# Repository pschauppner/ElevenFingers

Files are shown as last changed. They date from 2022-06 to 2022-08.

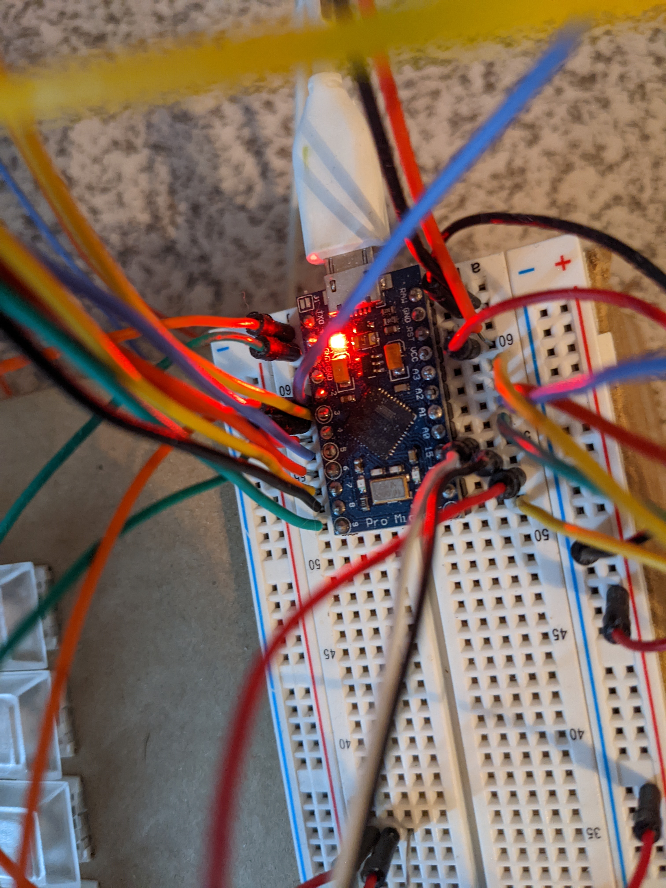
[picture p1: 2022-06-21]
pictures/PXL_20220617_202713375.jpg

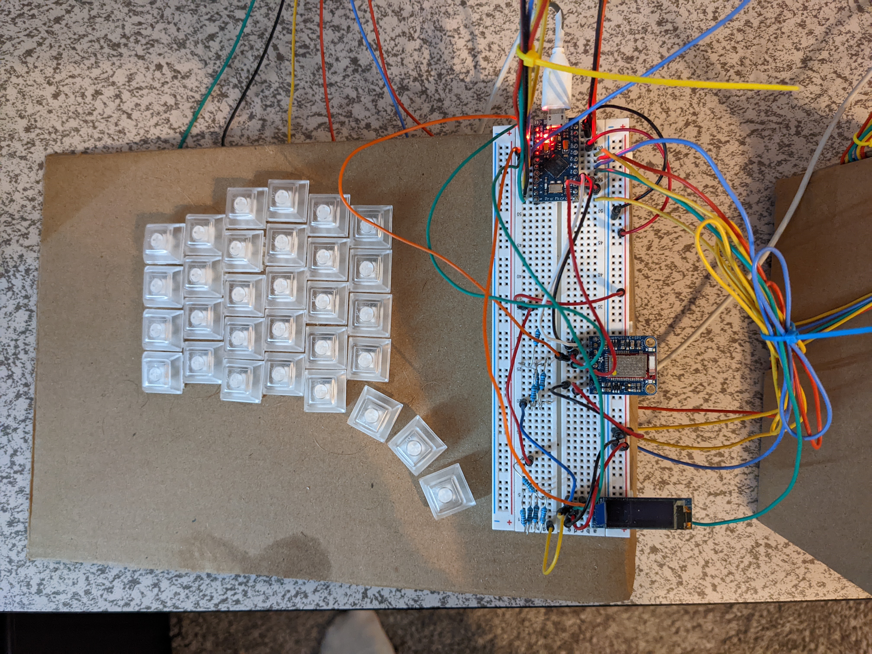
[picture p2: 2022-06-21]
pictures/PXL_20220617_202623680.jpg

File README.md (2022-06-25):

# ElevenFingers
An ergonomic split keyboard

## Notes/assumptions for this build
Encoder will be swapped in software (vice having a reverse footprint)
Most components are flipped for right side, LEDs are flipped AND rotated 180 degrees so that routes with vias can be more direct

## Issues and planned work
- Bluetooth is tempermental with pull down resistors - no longer needed for my current setup - plan to remove
- Source code has to get modified for flashing left half and right half - not great
- some software layout issues (no semi colon, tilde, grave, function keys...) - could really expand on use of layers
- OLED can be more helpful
- I don't like the sound of clicky keys - plan to switch to tactile
- hotswap sockets were a bad idea - they made connections less reliable (and I'm not a big keyswapper anyway)
- Next: case + PCB, better wires
- a power switch, and/or a reset button might be nice

## Project Navigation

### keyboard-layout-editor
This folder contains the json for uploading in the 'Raw Data' tab of [keyboard-layout-editor.com](http://www.keyboard-layout-editor.com/)
It's rotated right because it was easier for dealing with a columnar stagger this way (keyboard-layout-editor syntax is row-based, assuming each "row" is at the same vertical offset).

### qmk_firmware/keyboards/ElevenFingers
Contains the source code that would go under 'keyboards' in the qmk_firmware root directory (https://github.com/qmk/qmk_firmware)

Note - my idea is that any customizations to qmk will be added here with a script to copy it into the qmk repository.  (Why does QMK host so many individual keyboard source files?)

### fabrication
This keyboard is currently a cardboard prototype.  The svg was used as a template to cutout squares in a piece of cardboard.  In the future this will contain drawings for case and mounting plates.  Note I used http://builder.swillkb.com/ with the MX switch type (and otherwise default settings) to generate this SVG.

### circuitry
This keyboard was handwired.  This folder contains notes and pictures of the wiring.  In the future, this will contain PCB design files.

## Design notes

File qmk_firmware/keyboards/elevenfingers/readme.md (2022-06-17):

custom built split keyboard
cardboard prototype
Apr 17 2021
Paul Schauppner

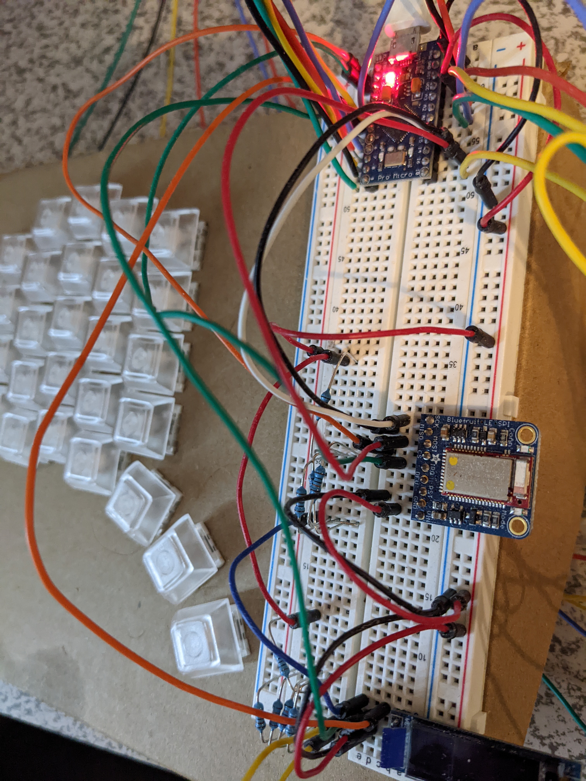
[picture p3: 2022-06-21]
pictures/PXL_20220617_202722207.MP.jpg

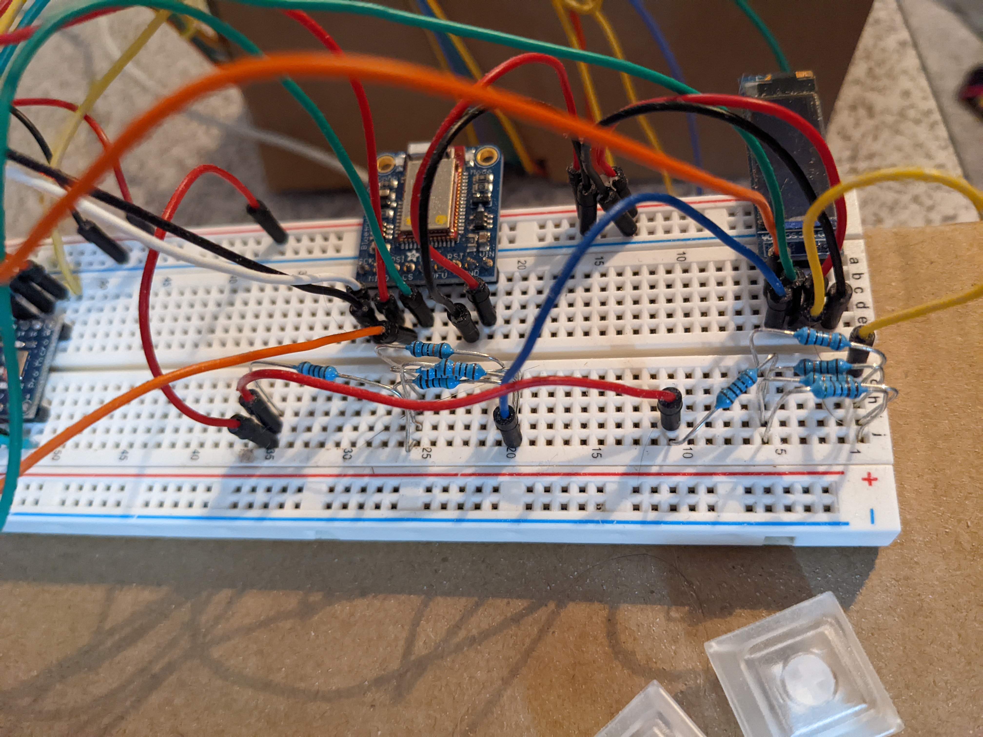
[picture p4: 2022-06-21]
pictures/PXL_20220617_202728293.MP.jpg

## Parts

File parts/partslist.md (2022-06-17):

100 - Kailh Hot-swap sockets (https://www.aliexpress.com/item/2255800865526224.html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)
2 - ATmega32U4 5V ProMicro (https://www.aliexpress.com/item/2251832803139947.html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)
70 - Kailh Box White RGB SMD switches (https://www.aliexpress.com/item/2251832649497008.html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)
200 - 1N4148 Diodes (https://www.aliexpress.com/item/2251832473773777.html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)
1 - SSD1306 OLED display (https://www.aliexpress.com/item/2255800842069517.html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)
60 - 1u PBT Blank Translucent Keycaps (https://www.aliexpress.com/item/2255800293762005.html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)
1 - Adafruit Bluefruit LE SPI

Wiring
Soldering Kit
Breadboards
Exacto Knife
Firm cardboard
Resistors
MicroUSB cable

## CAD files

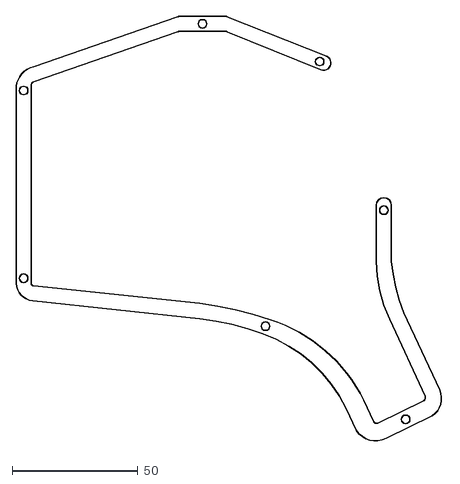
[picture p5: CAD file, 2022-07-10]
circuitry/case-files/ElevenFingers-User_2.dxf
169.8 x 169.7

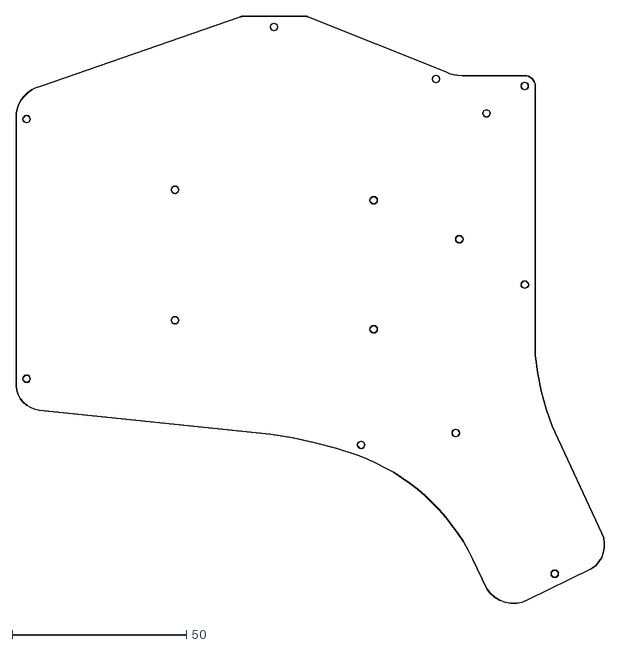
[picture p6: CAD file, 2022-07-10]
circuitry/case-files/ElevenFingers-User_4.dxf
169.8 x 169.7

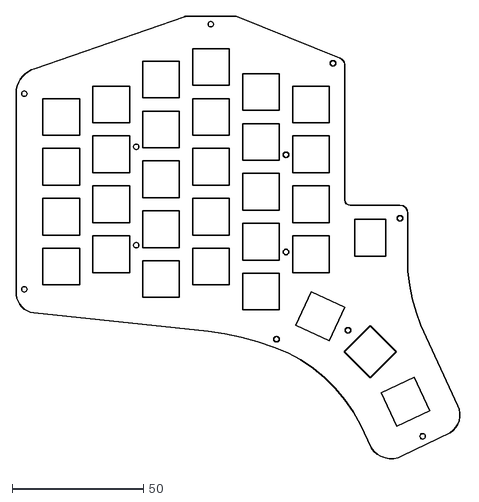
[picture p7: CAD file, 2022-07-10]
circuitry/case-files/ElevenFingers-User_3.dxf
169.8 x 169.7

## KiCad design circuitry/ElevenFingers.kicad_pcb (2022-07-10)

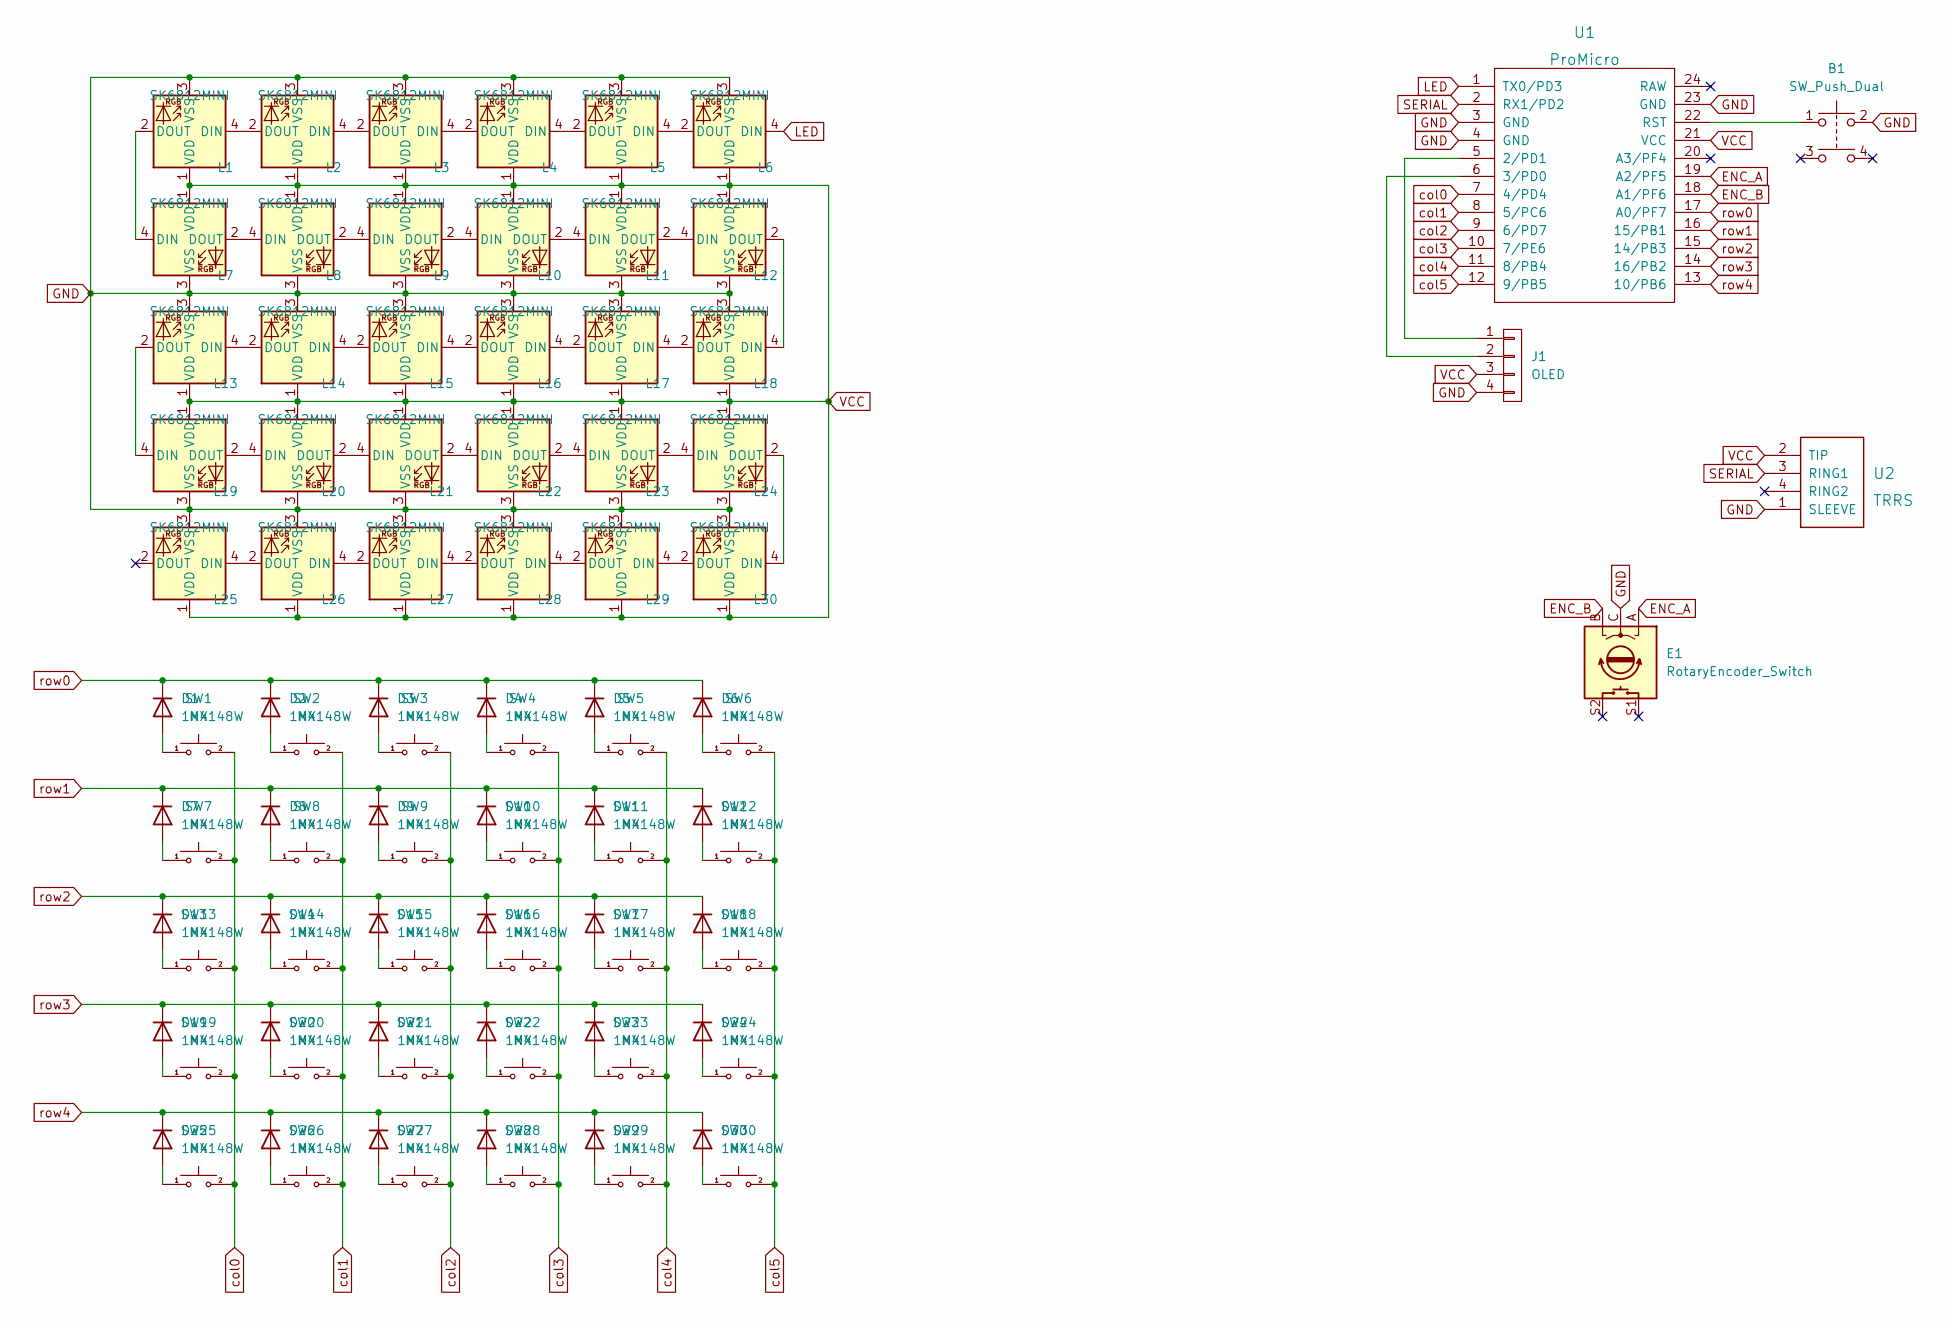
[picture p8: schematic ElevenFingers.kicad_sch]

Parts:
B1: SW_Push_Dual; Arduino_Pushbutton
D1, D2, D3, D4, D5, D6, D7, D8, D9, D10, D11, D12, D13, D14, D15, D16, D17, D18, D19, D20, D21, D22, D23, D24, D25, D26, D27, D28, D29, D30: 1N4148W; D_SOD-123
E1: RotaryEncoder_Switch; RotaryEncoder_EC11
J1: OLED; OLED_4Pin
L1, L2, L3, L4, L5, L6, L7, L8, L9, L10, L11, L12, L13, L14, L15, L16, L17, L18, L19, L20, L21, L22, L23, L24, L25, L26, L27, L28, L29, L30: SK6812MINI; LED_SK6812MINI_PLCC4_3.5x3.5mm_P1.75mm
SW1, SW2, SW3, SW4, SW5, SW6, SW7, SW8, SW9, SW10, SW11, SW12, SW13, SW14, SW15, SW16, SW17, SW18, SW19, SW20, SW21, SW22, SW23, SW24, SW25, SW26, SW27, SW28, SW29, SW30: MX; SW_Cherry_MX_1.00u_PCB
U1: ProMicro
U2: TRRS; TRRS-PJ-320A

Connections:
ENC_A: E1.A, U1.19 (A2/PF5)
ENC_B: E1.B, U1.18 (A1/PF6)
GND: B1.2, E1.C, J1.4, L1.3 (VSS), L2.3 (VSS), L3.3 (VSS), L4.3 (VSS), L5.3 (VSS), L6.3 (VSS), L7.3 (VSS), L8.3 (VSS), L9.3 (VSS), L10.3 (VSS), L11.3 (VSS), L12.3 (VSS), L13.3 (VSS), L14.3 (VSS), L15.3 (VSS), L16.3 (VSS), L17.3 (VSS), L18.3 (VSS), L19.3 (VSS), L20.3 (VSS), L21.3 (VSS), L22.3 (VSS), L23.3 (VSS), L24.3 (VSS), L25.3 (VSS), L26.3 (VSS), L27.3 (VSS), L28.3 (VSS), L29.3 (VSS), L30.3 (VSS), U1.3 (GND), U1.4 (GND), U1.23 (GND), U2.1 (SLEEVE)
LED: L6.4 (DIN), U1.1 (TX0/PD3)
unnamed: B1.1, U1.22 (RST)
unnamed: D1.2 (A), SW1.1
unnamed: D2.2 (A), SW2.1
unnamed: D3.2 (A), SW3.1
unnamed: D4.2 (A), SW4.1
unnamed: D5.2 (A), SW5.1
unnamed: D6.2 (A), SW6.1
unnamed: D7.2 (A), SW7.1
unnamed: D8.2 (A), SW8.1
unnamed: D9.2 (A), SW9.1
unnamed: D10.2 (A), SW10.1
unnamed: D11.2 (A), SW11.1
unnamed: D12.2 (A), SW12.1
unnamed: D13.2 (A), SW13.1
unnamed: D14.2 (A), SW14.1
unnamed: D15.2 (A), SW15.1
unnamed: D16.2 (A), SW16.1
unnamed: D17.2 (A), SW17.1
unnamed: D18.2 (A), SW18.1
unnamed: D19.2 (A), SW19.1
unnamed: D20.2 (A), SW20.1
unnamed: D21.2 (A), SW21.1
unnamed: D22.2 (A), SW22.1
unnamed: D23.2 (A), SW23.1
unnamed: D24.2 (A), SW24.1
unnamed: D25.2 (A), SW25.1
unnamed: D26.2 (A), SW26.1
unnamed: D27.2 (A), SW27.1
unnamed: D28.2 (A), SW28.1
unnamed: D29.2 (A), SW29.1
unnamed: D30.2 (A), SW30.1
unnamed: J1.1, U1.5 (2/PD1)
unnamed: J1.2, U1.6 (3/PD0)
unnamed: L1.2 (DOUT), L7.4 (DIN)
unnamed: L1.4 (DIN), L2.2 (DOUT)
unnamed: L2.4 (DIN), L3.2 (DOUT)
unnamed: L3.4 (DIN), L4.2 (DOUT)
unnamed: L4.4 (DIN), L5.2 (DOUT)
unnamed: L5.4 (DIN), L6.2 (DOUT)
unnamed: L7.2 (DOUT), L8.4 (DIN)
unnamed: L8.2 (DOUT), L9.4 (DIN)
unnamed: L10.2 (DOUT), L11.4 (DIN)
unnamed: L9.2 (DOUT), L10.4 (DIN)
unnamed: L11.2 (DOUT), L12.4 (DIN)
unnamed: L12.2 (DOUT), L18.4 (DIN)
unnamed: L13.2 (DOUT), L19.4 (DIN)
unnamed: L13.4 (DIN), L14.2 (DOUT)
unnamed: L14.4 (DIN), L15.2 (DOUT)
unnamed: L15.4 (DIN), L16.2 (DOUT)
unnamed: L16.4 (DIN), L17.2 (DOUT)
unnamed: L17.4 (DIN), L18.2 (DOUT)
unnamed: L19.2 (DOUT), L20.4 (DIN)
unnamed: L20.2 (DOUT), L21.4 (DIN)
unnamed: L21.2 (DOUT), L22.4 (DIN)
unnamed: L22.2 (DOUT), L23.4 (DIN)
unnamed: L23.2 (DOUT), L24.4 (DIN)
unnamed: L24.2 (DOUT), L30.4 (DIN)
unnamed: L25.4 (DIN), L26.2 (DOUT)
unnamed: L26.4 (DIN), L27.2 (DOUT)
unnamed: L27.4 (DIN), L28.2 (DOUT)
unnamed: L28.4 (DIN), L29.2 (DOUT)
unnamed: L29.4 (DIN), L30.2 (DOUT)
SERIAL: U1.2 (RX1/PD2), U2.3 (RING1)
VCC: J1.3, L1.1 (VDD), L2.1 (VDD), L3.1 (VDD), L4.1 (VDD), L5.1 (VDD), L6.1 (VDD), L7.1 (VDD), L8.1 (VDD), L9.1 (VDD), L10.1 (VDD), L11.1 (VDD), L12.1 (VDD), L13.1 (VDD), L14.1 (VDD), L15.1 (VDD), L16.1 (VDD), L17.1 (VDD), L18.1 (VDD), L19.1 (VDD), L20.1 (VDD), L21.1 (VDD), L22.1 (VDD), L23.1 (VDD), L24.1 (VDD), L25.1 (VDD), L26.1 (VDD), L27.1 (VDD), L28.1 (VDD), L29.1 (VDD), L30.1 (VDD), U1.21 (VCC), U2.2 (TIP)
col0: SW1.2, SW7.2, SW13.2, SW19.2, SW25.2, U1.7 (4/PD4)
col1: SW2.2, SW8.2, SW14.2, SW20.2, SW26.2, U1.8 (5/PC6)
col2: SW3.2, SW9.2, SW15.2, SW21.2, SW27.2, U1.9 (6/PD7)
col3: SW4.2, SW10.2, SW16.2, SW22.2, SW28.2, U1.10 (7/PE6)
col4: SW5.2, SW11.2, SW17.2, SW23.2, SW29.2, U1.11 (8/PB4)
col5: SW6.2, SW12.2, SW18.2, SW24.2, SW30.2, U1.12 (9/PB5)
row0: D1.1 (K), D2.1 (K), D3.1 (K), D4.1 (K), D5.1 (K), D6.1 (K), U1.17 (A0/PF7)
row1: D7.1 (K), D8.1 (K), D9.1 (K), D10.1 (K), D11.1 (K), D12.1 (K), U1.16 (15/PB1)
row2: D13.1 (K), D14.1 (K), D15.1 (K), D16.1 (K), D17.1 (K), D18.1 (K), U1.15 (14/PB3)
row3: D19.1 (K), D20.1 (K), D21.1 (K), D22.1 (K), D23.1 (K), D24.1 (K), U1.14 (16/PB2)
row4: D25.1 (K), D26.1 (K), D27.1 (K), D28.1 (K), D29.1 (K), D30.1 (K), U1.13 (10/PB6)

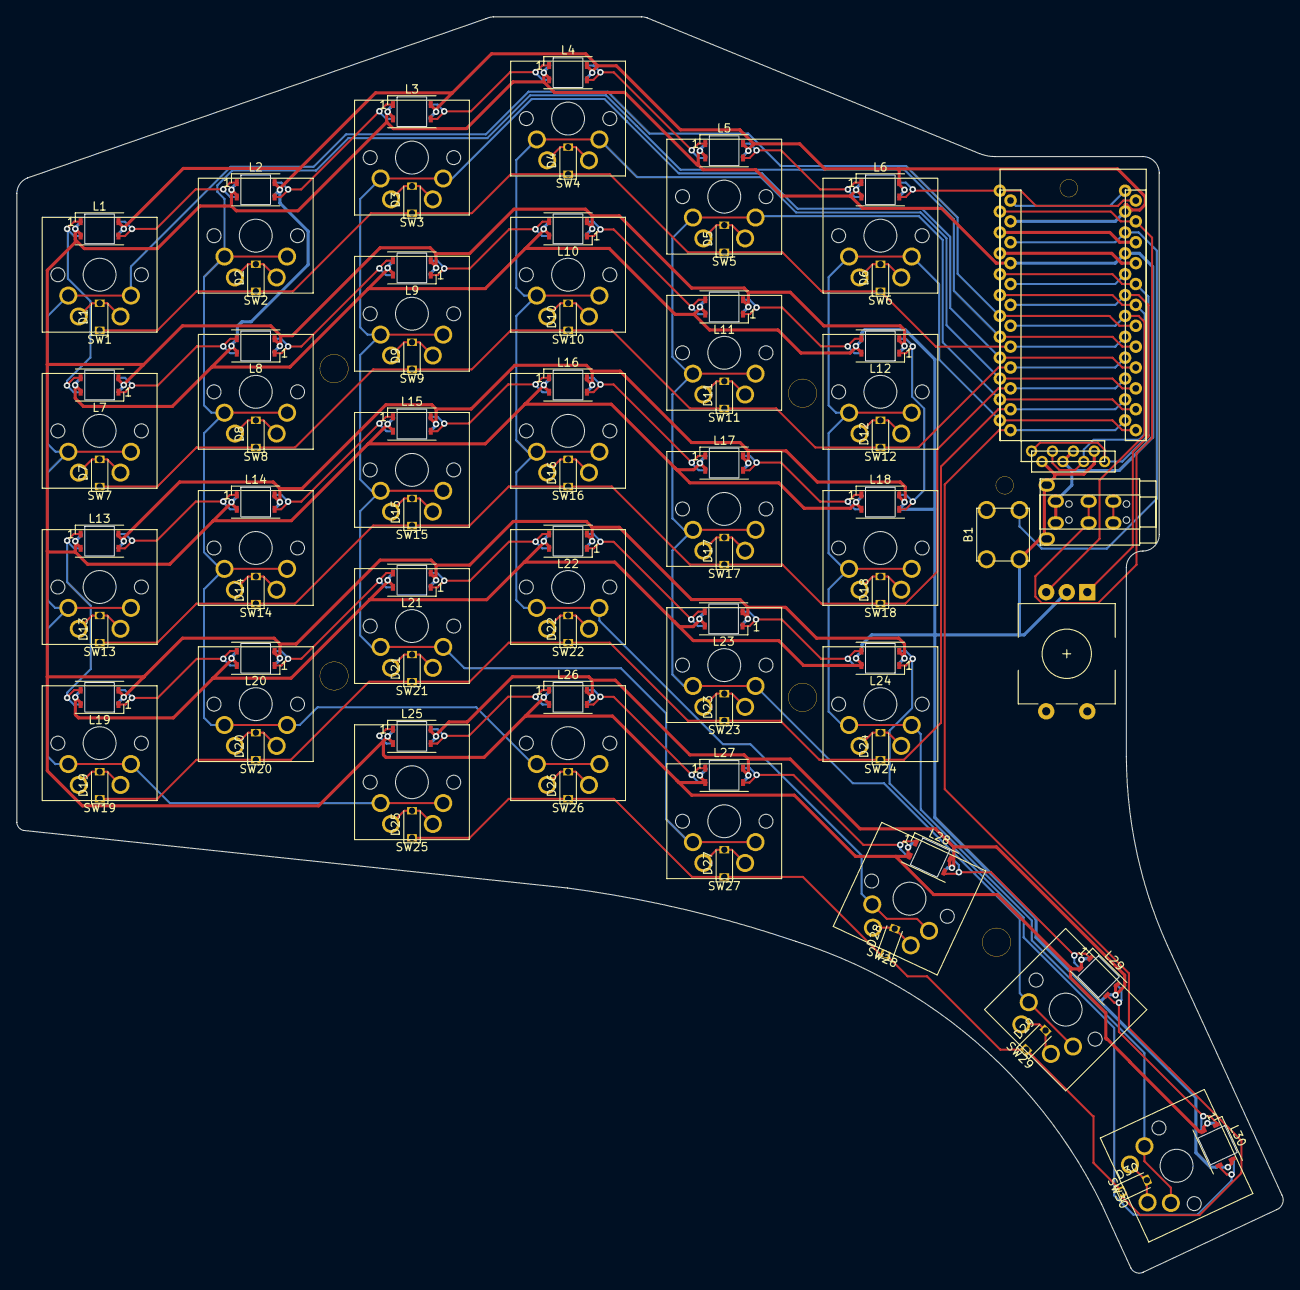
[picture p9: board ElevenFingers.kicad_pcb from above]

Board: 2 copper layers, 154.1 x 152.9 mm, 95 parts (0 on the bottom side), 79 nets.

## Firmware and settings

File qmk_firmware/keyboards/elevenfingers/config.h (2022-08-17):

/*
Copyright 2021 Paul Schauppner <pschauppner@gmail.com>

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
You should have received a copy of the GNU General Public License
along with this program.  If not, see <http://www.gnu.org/licenses/>.
*/

#ifndef CONFIG_H
#define CONFIG_H

#include "config_common.h"

#define ENCODERS_PAD_A {F6}
#define ENCODERS_PAD_B {F5}
#define ENCODERS_PAD_A_RIGHT {F5}
#define ENCODERS_PAD_B_RIGHT {F6}

/* USB Device descriptor parameter */
#define VENDOR_ID       0xFEED
#define PRODUCT_ID      0x0007
#define DEVICE_VER 		0x0001
#define MANUFACTURER    none
#define PRODUCT         ElevenFingers

/* key matrix size */
#define MATRIX_ROWS 10
#define MATRIX_COLS 6

/* ElevenFingers PCB default pin-out */
#define MATRIX_ROW_PINS { F7, B1, B3, B2, B6}
#define MATRIX_COL_PINS { D4, C6, D7, E6, B4, B5}
#define MATRIX_COL_PINS_RIGHT { B5, B4, E6, D7, C6, D4 }

#define UNUSED_PINS

/* ws2812 RGB LED */
#define RGB_DI_PIN D3
#define DRIVER_LED_TOTAL 60    // Number of LEDs
//#define RGBLED_SPLIT { 30, 30 }
//#define RGBLIGHT_SPLIT
#define RGB_MATRIX_SPLIT { 30, 30 }
#define RGB_MATRIX_MAXIMUM_BRIGHTNESS 120
#define SPLIT_TRANSPORT_MIRROR

//#define ENABLE_RGB_MATRIX_SOLID_COLOR
#define ENABLE_RGB_MATRIX_CYCLE_LEFT_RIGHT


/* COL2ROW or ROW2COL */
#define DIODE_DIRECTION COL2ROW

#define TAPPING_TERM 200

#define LEADER_TIMEOUT 500
#define LEADER_PER_KEY_TIMING

//#define SPLIT_USB_DETECT
#define MASTER_LEFT

//for serial
#define SOFT_SERIAL_PIN D2
#define SELECT_SOFT_SERIAL_SPEED 5

//for i2c
//#define USE_I2C
//#define RIGHT_HALF_INT_I2C_PULLUPS_OFF

#endif

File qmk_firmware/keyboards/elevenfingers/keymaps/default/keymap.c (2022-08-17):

//TODO - how to get into nav layer
//TODO - encoder mappings
//TODO - left right oled
#include QMK_KEYBOARD_H

#define _BASE 0
#define _SHIFT 1
#define _NAV 2
#define _NUM 3

#ifdef ENCODER_MAP_ENABLE
const uint16_t PROGMEM encoder_map[][NUM_ENCODERS][2] = {
[_BASE]  =  { ENCODER_CCW_CW(KC_KB_VOLUME_DOWN, KC_KB_VOLUME_UP), ENCODER_CCW_CW(RGB_VAD, RGB_VAI) },     // volume, todo-scroll though open apps
[_SHIFT] =  { ENCODER_CCW_CW(RGB_RMOD, RGB_MOD),                  ENCODER_CCW_CW(RGB_HUD, RGB_HUI) },                       // unused (left thumb occupied), todo - scroll thorugh browser tabs
[_NAV]   =  { ENCODER_CCW_CW(KC_MS_WH_LEFT, KC_MS_WH_RIGHT),      ENCODER_CCW_CW(KC_MS_WH_UP, KC_MS_WH_DOWN) },             // scroll left/right up/down in nav layer
[_NUM]   =  { ENCODER_CCW_CW(KC_MS_LEFT, KC_MS_RIGHT),            ENCODER_CCW_CW(KC_MS_UP, KC_MS_DOWN) }                    // tbd
};
#endif

/* Implementing as "_Shift" layer
const key_override_t colon_key_override = ko_make_basic(KC_LSFT, KC_COLN, KC_SEMICOLON);

// This globally defines all key overrides to be used
const key_override_t **key_overrides = (const key_override_t *[]){
    &colon_key_override,
    NULL // Null terminate the array of overrides!
};
*/

//Tap dance defs
enum {
        TD_QUOT,
        TD_TLDA,
        TD_LPRN,
        TD_RPRN,
};

void dance_quot_finished(qk_tap_dance_state_t *state, void *user_data){
        switch(state->count){
                case 1:
                        register_code16(KC_QUOTE);
                        break;
                case 2:
                        register_code(KC_GRAVE);
                        break;
        }
}

void dance_quot_reset(qk_tap_dance_state_t *state, void *user_data){
        switch(state->count){
                case 1:
                        unregister_code16(KC_QUOTE);
                        break;
                case 2:
                        unregister_code(KC_GRAVE);
                        break;
        }
}

void dance_tilda_finished(qk_tap_dance_state_t *state, void *user_data){
        switch(state->count){
                case 1:
                        register_code16(KC_MINUS);
                        break;
                case 2:
                        register_code16(KC_TILDE);
                        break;
        }
}

void dance_tilda_reset(qk_tap_dance_state_t *state, void *user_data){
        switch(state->count){
                case 1:
                        unregister_code16(KC_MINUS);
                        break;
                case 2:
                        unregister_code16(KC_TILDE);
                        break;
        }
}

void dance_left_paren_finished(qk_tap_dance_state_t *state, void *user_data){
        switch(state->count){
                case 1:
                        register_code16(KC_LEFT_PAREN);
                        break;
                case 2:
                        register_code(KC_LBRACKET);
                        break;
                case 3:
                        register_code16(KC_LEFT_CURLY_BRACE);
                        break;
        }
}

void dance_left_paren_reset(qk_tap_dance_state_t *state, void *user_data){
        switch(state->count){
                case 1:
                        unregister_code16(KC_LEFT_PAREN);
                        break;
                case 2:
                        unregister_code(KC_LBRACKET);
                        break;
                case 3:
                        unregister_code16(KC_LEFT_CURLY_BRACE);
                        break;
        }
}

void dance_right_paren_finished(qk_tap_dance_state_t *state, void *user_data){
        switch(state->count){
                case 1:
                        register_code16(KC_RIGHT_PAREN);
                        break;
                case 2:
                        register_code(KC_RBRACKET);
                        break;
                case 3:
                        register_code16(KC_RIGHT_CURLY_BRACE);
                        break;
        }
}

void dance_right_paren_reset(qk_tap_dance_state_t *state, void *user_data){
        switch(state->count){
                case 1:
                        unregister_code16(KC_RIGHT_PAREN);
                        break;
                case 2:
                        unregister_code(KC_RBRACKET);
                        break;
                case 3:
                        unregister_code16(KC_RIGHT_CURLY_BRACE);
                        break;
        }
}

qk_tap_dance_action_t tap_dance_actions[] = {
        [TD_QUOT] = ACTION_TAP_DANCE_FN_ADVANCED(NULL, dance_quot_finished, dance_quot_reset),
        [TD_TLDA] = ACTION_TAP_DANCE_FN_ADVANCED(NULL, dance_tilda_finished, dance_tilda_reset),
        [TD_LPRN] = ACTION_TAP_DANCE_FN_ADVANCED(NULL, dance_left_paren_finished, dance_left_paren_reset),
        [TD_RPRN] = ACTION_TAP_DANCE_FN_ADVANCED(NULL, dance_right_paren_finished, dance_right_paren_reset)
};

const uint16_t PROGMEM keymaps[][MATRIX_ROWS][MATRIX_COLS] = {

[_BASE] = LAYOUT( \
  RGB_TOG,  KC_0,     KC_1,     KC_2,  KC_UNDS,   TD(TD_QUOT),                                           TD(TD_LPRN), TD(TD_RPRN),  KC_MINS,  KC_PLUS,   KC_EQL, KC_BSPC, \
  _______,  KC_Q,     KC_W,     KC_F,     KC_P,          KC_B,                                                  KC_J,        KC_L,     KC_U,     KC_Y,  KC_COLN,  KC_DEL, \
  KC_LEAD,  KC_A,     KC_R,     KC_S,     KC_T,          KC_G,                                                  KC_M,        KC_N,     KC_E,     KC_I,     KC_O,  KC_ENT, \
  KC_LGUI,  KC_Z,     KC_X,     KC_C,     KC_D,          KC_V,                                                  KC_K,        KC_H,  KC_COMM,   KC_DOT,  KC_SLSH, KC_BSLS, \
                  TO(_NAV), TO(_NUM),  KC_LALT,    MO(_SHIFT),  KC_LCTL,  MO(_NUM),      MO(_NAV),  KC_TAB,   KC_SPC,      KC_INS,  _______,  _______ \
),

[_SHIFT] = LAYOUT( \
  _______,  S(KC_0),  S(KC_1),  S(KC_2),   KC_MINS, S(KC_QUOT),                                                     KC_LCBR,  KC_RCBR,    KC_TILD,   _______,     _______, S(KC_BSPC), \
  _______,  S(KC_Q),  S(KC_W),  S(KC_F),   S(KC_P),    S(KC_B),                                                     S(KC_J),  S(KC_L),    S(KC_U),   S(KC_Y),     KC_SCLN,  S(KC_DEL), \
  _______,  S(KC_A),  S(KC_R),  S(KC_S),   S(KC_T),    S(KC_G),                                                     S(KC_M),  S(KC_N),    S(KC_E),   S(KC_I),     S(KC_O),  S(KC_ENT), \
  _______,  S(KC_Z),  S(KC_X),  S(KC_C),   S(KC_D),    S(KC_V),                                                     S(KC_K),  S(KC_H), S(KC_COMM), S(KC_DOT),  S(KC_SLSH), S(KC_BSLS), \
                     TO(_NAV), TO(_NUM),S(KC_LALT),    _______,  S(KC_LCTL),  MO(_NUM),      MO(_NAV), S(KC_TAB), S(KC_SPC), S(KC_INS),  _______,  _______ \
),
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

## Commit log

2022-06-17 fixed folder structure to match qmk_firmware
    [config.h, keymap.c]
2022-06-21 complete prototype board
    [ElevenFingers.kicad_pcb, ElevenFingers.kicad_sch]
2022-06-21 moved row0-4 and col0-5 pins
    [ElevenFingers.kicad_sch]
2022-06-24 finished schematic, customized footprints, organized pcb
    [ElevenFingers.kicad_pcb, ElevenFingers.kicad_sch]
2022-06-24 keys all placed, 1 led placed, no tracing yet
    [ElevenFingers.kicad_pcb]
2022-06-25 started adding tracing
    [ElevenFingers.kicad_pcb]
2022-06-25 all components traced internally, not yet connected
    [ElevenFingers.kicad_pcb, ElevenFingers.kicad_sch]
2022-06-25 routed rows
    [ElevenFingers.kicad_pcb]
2022-06-25 routed columns
    [ElevenFingers.kicad_pcb]
2022-06-25 rotated leds on alternating rows
    [ElevenFingers.kicad_pcb]
2022-06-25 routed data for led rows (have not connected rows)
    [ElevenFingers.kicad_pcb]
2022-06-25 routed rows and cols to ProMicro
    [ElevenFingers.kicad_pcb]
2022-06-25 pwr and gnd routed for leds, (not to promicro, and not across rows)
    [ElevenFingers.kicad_pcb]
2022-06-26 completed tracing?
    [ElevenFingers.kicad_pcb]
2022-06-26 finished tracing and error checking
    [ElevenFingers.kicad_pcb]
2022-06-27 tightened horizontal spacing of components
    [ElevenFingers.kicad_pcb]
2022-07-08 completed plate layers and edge cuts
    [ElevenFingers.kicad_pcb]
2022-07-10 changed pcb holes to NPTH, mechanical, generated case dxf files
    [ElevenFingers-B_Cu.gbr, ElevenFingers-B_Mask.gbr, ElevenFingers-B_Paste.gbr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]

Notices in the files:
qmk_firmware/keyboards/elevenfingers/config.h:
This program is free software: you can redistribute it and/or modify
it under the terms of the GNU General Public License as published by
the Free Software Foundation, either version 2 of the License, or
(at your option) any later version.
